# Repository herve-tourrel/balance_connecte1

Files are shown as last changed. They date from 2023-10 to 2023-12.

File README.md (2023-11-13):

# Balance_connectée
Encore une balance connectée pour peser nos ruches.
Cette version contrairement à ce que j'ai pu trouvé sur le net est voulu entiérement paramétrable par l'utilisateur sans aucune intervension de reprogrammation du microcontroleur.
Elle peut_être utilisée avec n'importe quel type de pont de mesures puisque le calibrage se fait à partir du site web embarqué.

Pour le moment elle n'est prévue que pour envoyer la masse de la ruche à l'utilisateur par un SMS. Le nombre de SMS par jour et l'heure d'envoi sont paramétrable par l'interface WEB.

Le site web embarqué n'est accessible que proche de la balance et à condition de l'avoir mis en service. En fonctionnement normal le site web est arrété pour des questions de sécurité et d'économie d'énergie.

## Images du serveur web embarqué

<p align="center">
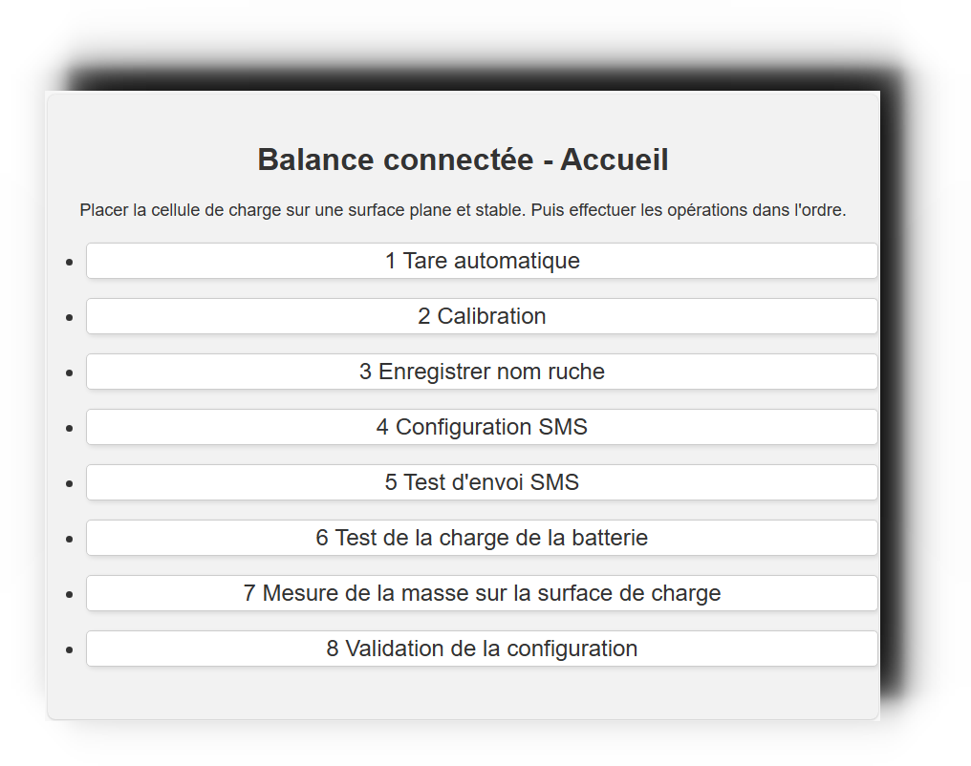
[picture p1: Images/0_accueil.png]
Accueil
  
</p>

## Constitution de la balance
<p align="center">
Cette balance est construite autour d'un ESP32 WROOM de chez 
</p>
<p align="center">
esp32
</p>
<p align="center">
basée sur une carte A7608 de chez Lilygo
</p>
<p align="center">
 A7608
</p>
<p align="center">
Cette carte intégre tout ce qu'il nous faut sauf le convertisseur Analogique Numérique Amplificateur HX711
</p>
<p align="center">
A7608
</p>

Au dos de cette carte il ya un support pour la batterie LI-ion 18650 et sur le devant :
* un emplacement pour la carte SIM
* le module A7608 compatible 4G
* un connecteur pour panneau solaire pour recharger la batterie

**Pour la commande du composant principal voici le lien direct sur le site du fabricant:**

<p align="center">
https://www.lilygo.cc/products/t-a7608e-h?bg_ref=ym9qhdJWHc
</p>

**Pour les connecteurs :**

 https://fr.aliexpress.com/item/1005003084329744.html
 
 Il faut prendre la "couleur" : back nut  qui correspond au montage dans un trou de 13mm.
 Il faut ensuite prendre :
 * un 2P pour le panneau solaire extérieur
 * un 3P pour la configuration et l'anti-soulévement ( Attention il faut 2 connecteurs male pour une balance ( un seul suplémentaires pour la configuration de plusieurs balances)
 * un 5P pour la connection au pont de mesure de masse

**Pour le boitier :**

 https://fr.aliexpress.com/item/1005001304761174.html
 
Boîtier étanche transparent en plastique IP67
 * Taille : with ears
 * Couleur : 200-120-75 (Taille)

**Le prototype :**

<p align="center">
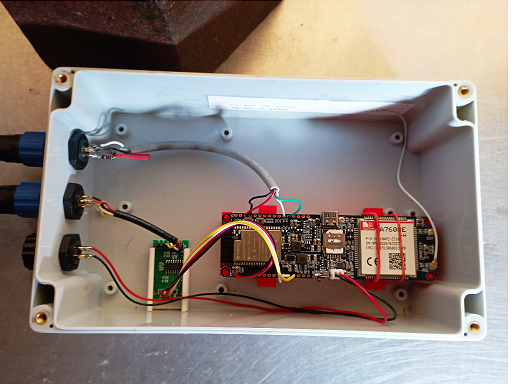
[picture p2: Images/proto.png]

</p>

**Le schéma du module de pesage :**
<p align="center">
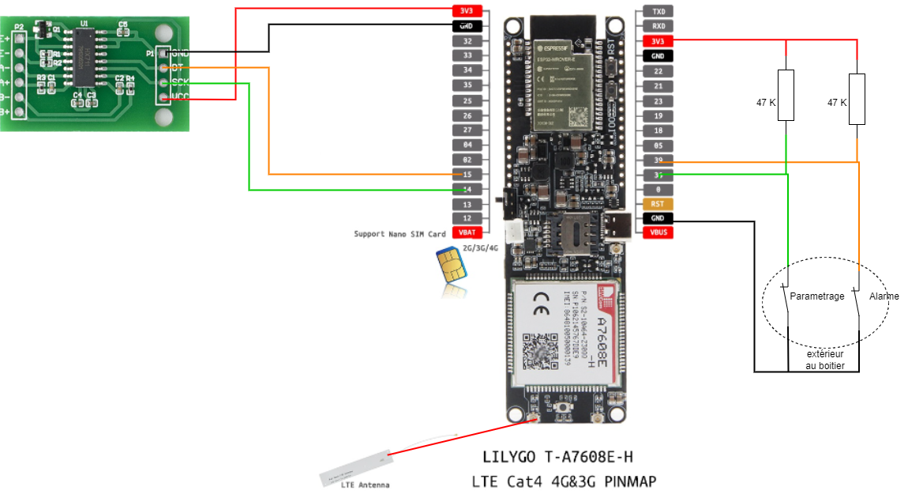
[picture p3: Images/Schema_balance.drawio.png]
Schema

</p>

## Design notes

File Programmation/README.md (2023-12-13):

# Programmation :

Deux maniéres de faire :

##  1 Utilisation d'ESP Web Tools

Pour programmer directement à partir de la page Web[ Lien vers la page de programmation](https://herve-tourrel.github.io/balance_connecte1/flash.html).

## 2 Utilisation d'ESP Tool

### Instructions

1. Copiez la totalité du dossier **test** dans un répertoire de votre poste de travail.
2. Ouvrez la page web[ ESP Tool ](https://espressif.github.io/esptool-js/)
3. Connectez votre carte à votre poste de travail
4. Puis appuyez sur **Connect** :
5. Choisissez le bon port de communication, pour moi ici le 17 :           
6. Puis appuyez sur **Connexion** :                                            
7. Vous devez voir dans la console (partie en noir) quelque chose comme ça :
8. En plus du premier fichier proposé il faut ajouter 4 autres fichiers en cliquant sur le bouton Add File. C'est les fichiers que vous avez copiés sur votre poste de travail. 
9. Vous devez obtenir ceci, attention à bien remplir la case Flash Adress pour chacuns des fichiers.
10. Ensuite vous pouvez appuyer sur le bouton **Program** à coté de Add File. Vous devriez voir dans la console quelque chose comme ça :
11. Une fois la programmation terminée, vous devez vous deconnecter du mode programmation avec le bouton **Disconnect** : 
12. Puis maintenant, vous connectez à la console avec le bouton **Start** : 
13. De nouveau choissisez le bon port de communication de votre carte (ici le 17) puis **Connexion** : 
14. Il faut ensuite faire un **Reset** :
15. Dans la console maintenant vous devriez voir quelque chose comme ça :

## 3 Derniére solution.

Téléchargez le logiciel [Flash Download Tool](https://www.espressif.com/en/support/download/other-tools).

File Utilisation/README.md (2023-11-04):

Pour utiliser la balance , la premiére des choses est de la paramétrer par le serveur web.
## Accés au serveur web embarqué

Le "Bouchon Paramétrage" , connecteur mâle à 3 broches modifiés permet de lancer le réseau Wifi et le serveur Web. 

**Le câblage du bouchon de paramétrage :**

<p align="center">
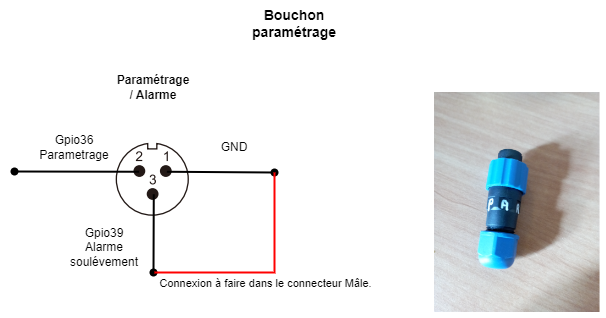
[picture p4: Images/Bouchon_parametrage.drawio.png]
Bouchon

</p>

Il faut dans un premier temps se connecter au réseau Wifi "Bal_Con_07" créé par la balance :

Pour aider à la connexion on peut utiliser ce QR code.

<p align="center">
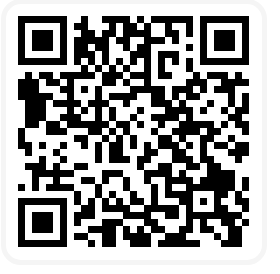
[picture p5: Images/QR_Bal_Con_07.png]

</p>

Ensuite il faut se connecter au serveur web à l'adresse 192.168.1.1 .

Pour aider à la connexion on peut utiliser ce QR code.

<p align="center">
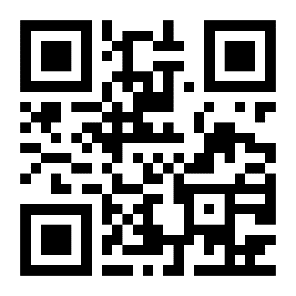
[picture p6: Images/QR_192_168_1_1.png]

</p>

Attention il faut souvent enlever les données mobiles pour pouvoir se connecter à ce serveur WEB.

## Images du serveur web embarqué

Accueil

## Vidéo de configuration de la balance connectée

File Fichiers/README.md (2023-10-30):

## Fichiers source

Ce dossier contient le fichier .cpp qui est le code de la balance puis les fichiers .html et .css pour le serveur web

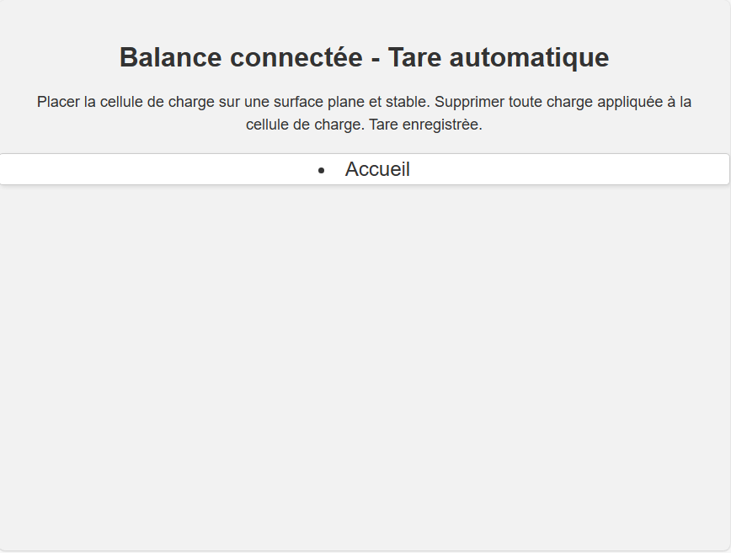
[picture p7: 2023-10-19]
Images/origine_web/1_tare_reponse.png

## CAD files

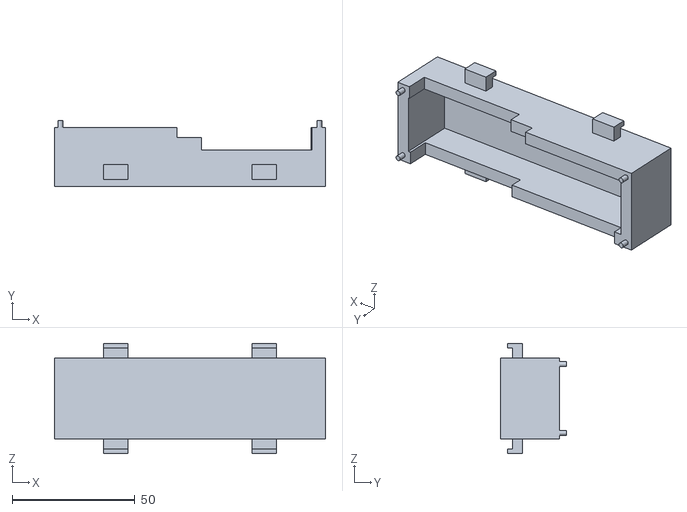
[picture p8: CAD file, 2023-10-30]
Fichiers/stl/piece lilygo.STL
110.5 x 27.0 x 45.0

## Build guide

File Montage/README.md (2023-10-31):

## Montage de la balance.
Le montage du pont de mesure ne sera pas expliqué ici, chacun prendra la solution qui lui convient le mieux en fonction de ses talents de bricoleur.
Mais plus bas il y aura les solutions testées.

Pour la commande du composant principal voici le lien direct sur le site du fabricant:

<p align="center">
 https://www.lilygo.cc/products/t-a7608e-h?bg_ref=ym9qhdJWHc
 </p>

## Solution n°1 employée :

## Solution n°2 employée :

**Le schéma du module de pesage :**
<p align="center">
Schema
</p>

**Le schéma du câblage des connecteurs extérieurs :**
<p align="center">
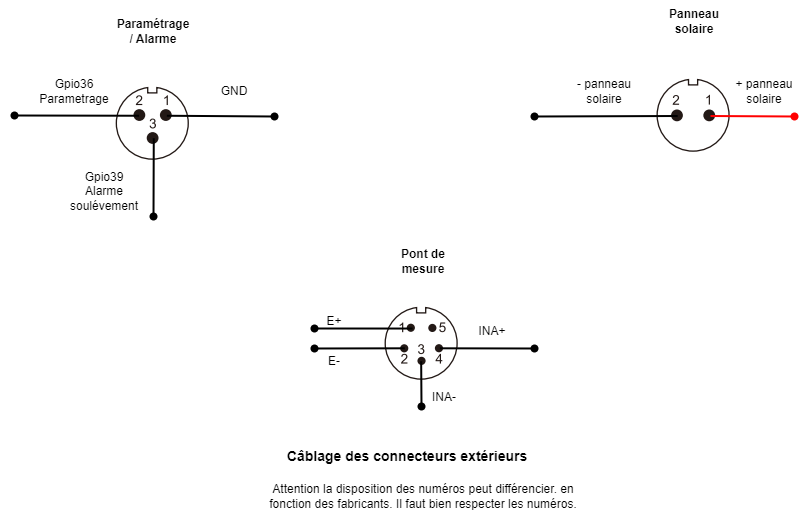
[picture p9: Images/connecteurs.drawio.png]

</p>

**Les connecteurs extérieurs :**
<p align="center">
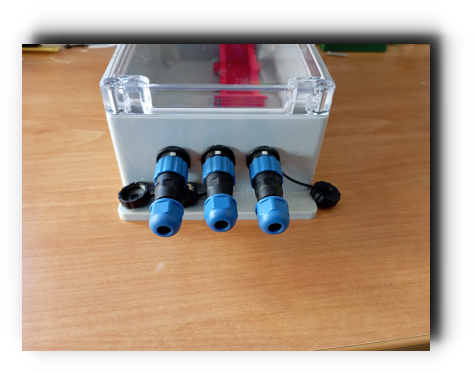
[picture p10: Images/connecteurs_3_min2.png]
connecteurs

</p>

**Les connecteurs extérieurs :**
<p align="center">
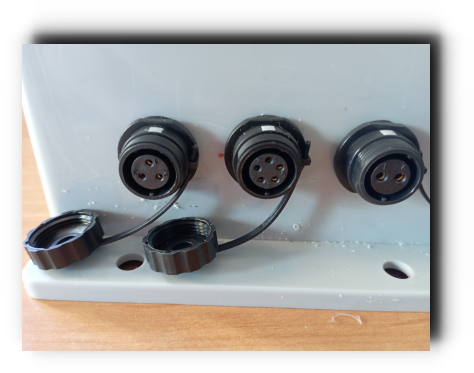
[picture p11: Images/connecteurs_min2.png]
connecteurs

</p>

**Les connecteurs extérieurs :**
<p align="center">
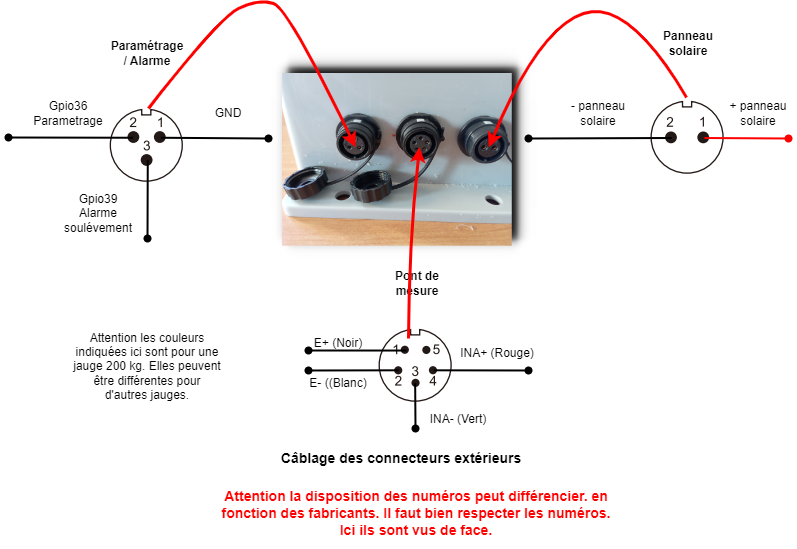
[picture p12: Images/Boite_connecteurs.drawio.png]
connecteurs

</p>

**Les connecteurs extérieurs perçage :**
<p align="center">
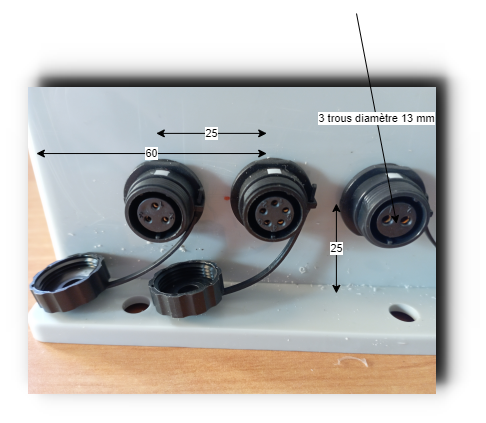
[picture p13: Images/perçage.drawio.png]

</p>

**Le support de la platine principale dit "La baignoire" :**
<p align="center">
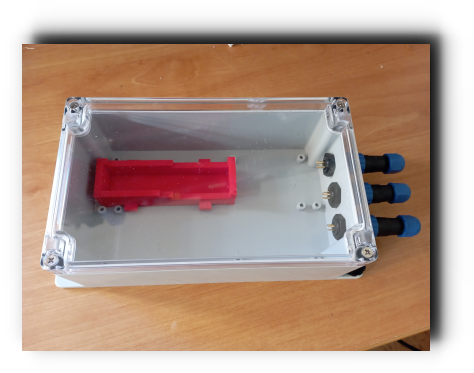
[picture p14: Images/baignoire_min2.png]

</p>

"La baignoire" est simplement collée avec de la colle PVC pour tuyau au fond du boitier. 

Le lien de téléchargement du fichier STL de ["La baignoire"](https://github.com/herve-tourrel/balance_connecte1/blob/main/Fichiers/stl/piece%20lilygo.STL).

**L'élastique pour maintenir la platine principale dans "La baignoire" :**
<p align="center">
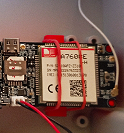
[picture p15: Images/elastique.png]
Elastique

</p>

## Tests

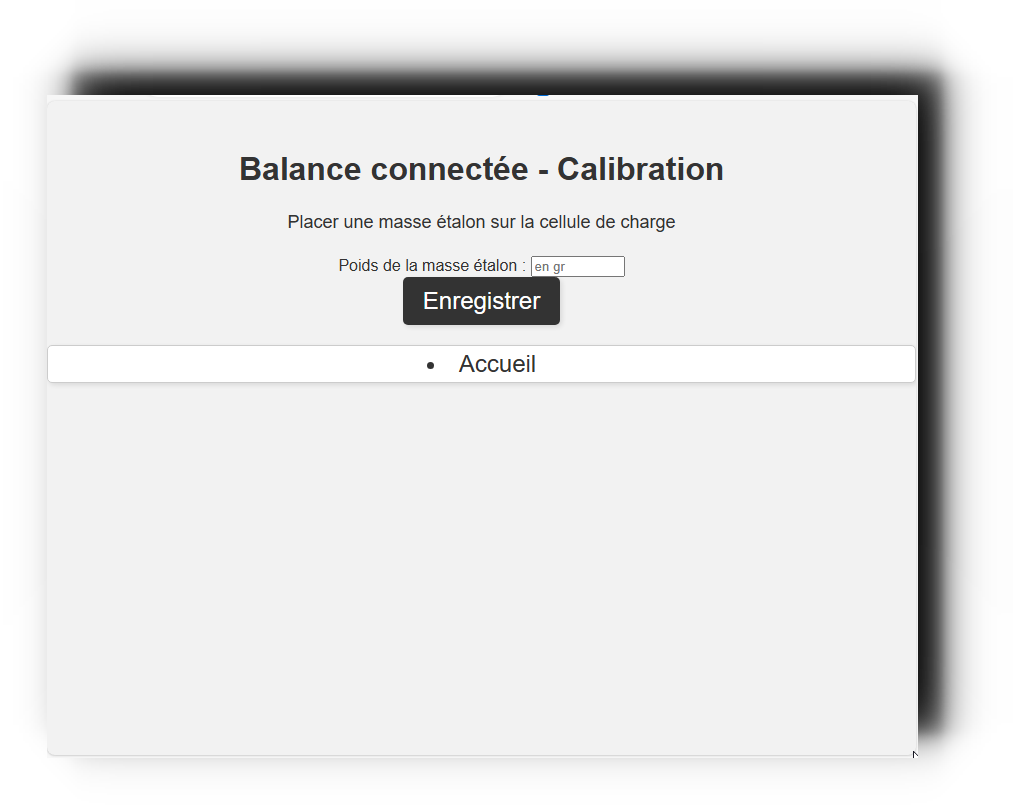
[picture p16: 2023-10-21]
Images/2_calibration.png

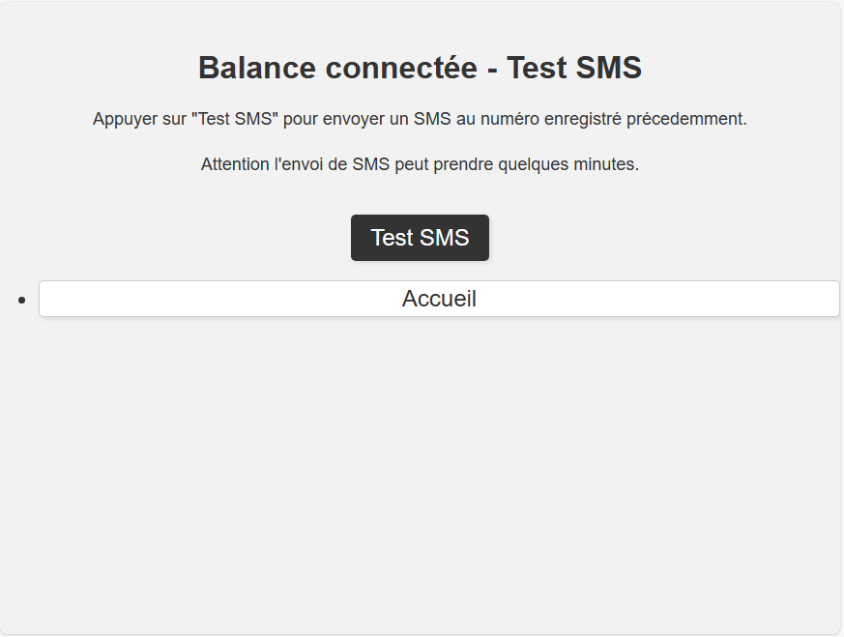
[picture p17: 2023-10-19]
Images/origine_web/5_test_sms.png

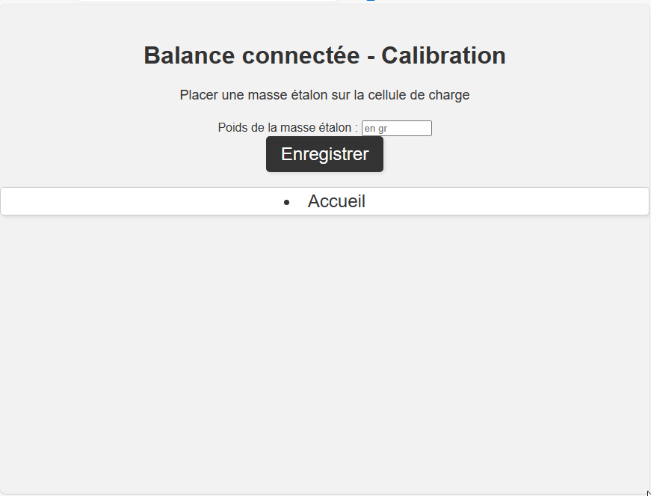
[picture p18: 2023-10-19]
Images/origine_web/2_calibration.png

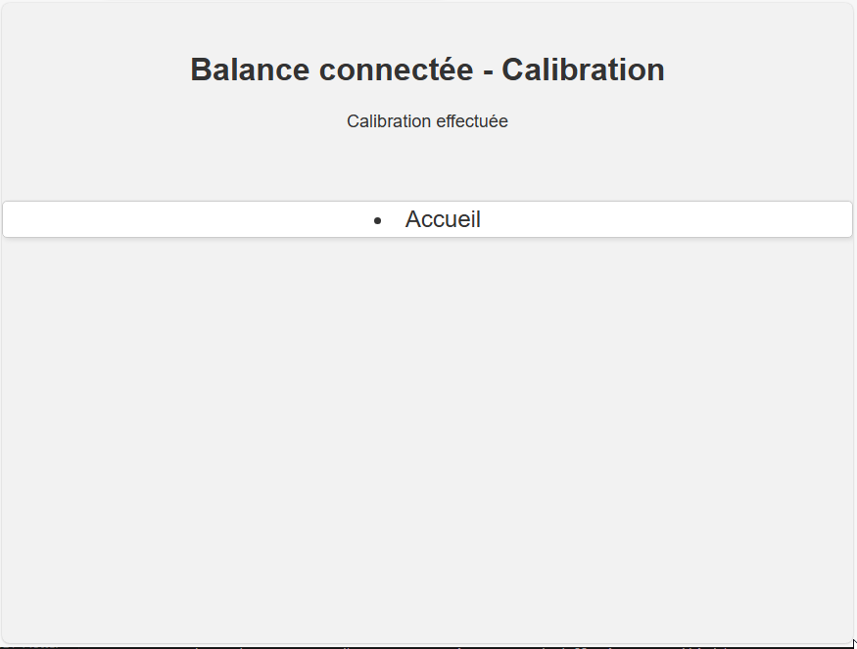
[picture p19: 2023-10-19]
Images/origine_web/2_calibration_reponse.png

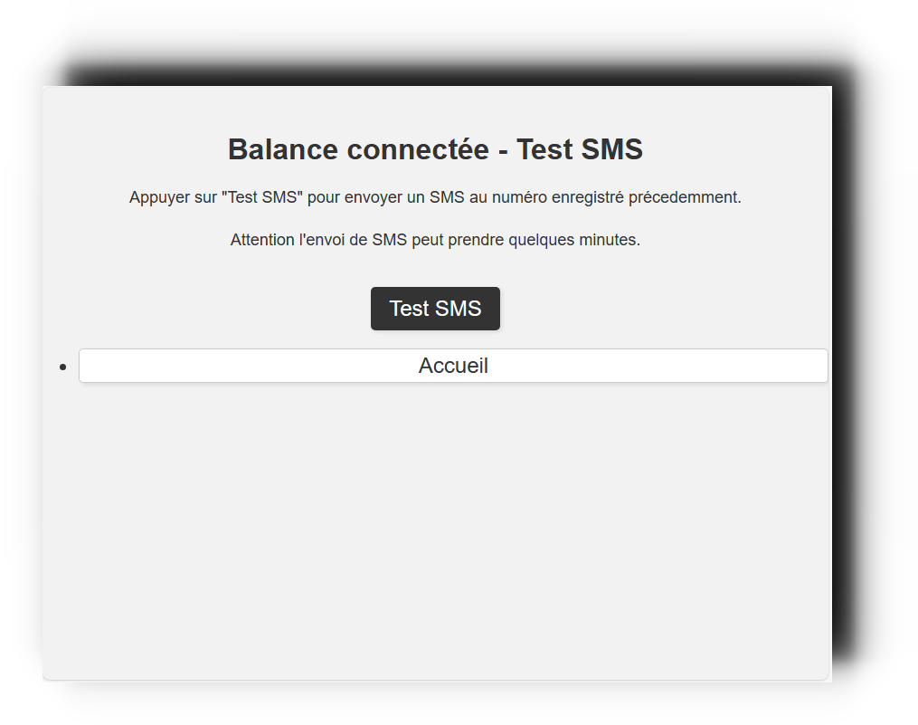
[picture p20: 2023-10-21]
Images/5_test_sms.png

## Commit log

2023-10-19 ajout des images
    ajout des images
2023-10-30 ajout html
    [piece lilygo.STL]
2023-11-08 Create Jauge 200Kg.drawio.png
2023-11-29 creation test
    creation de test
